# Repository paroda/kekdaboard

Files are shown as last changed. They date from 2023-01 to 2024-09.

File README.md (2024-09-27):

# Custom keyboard

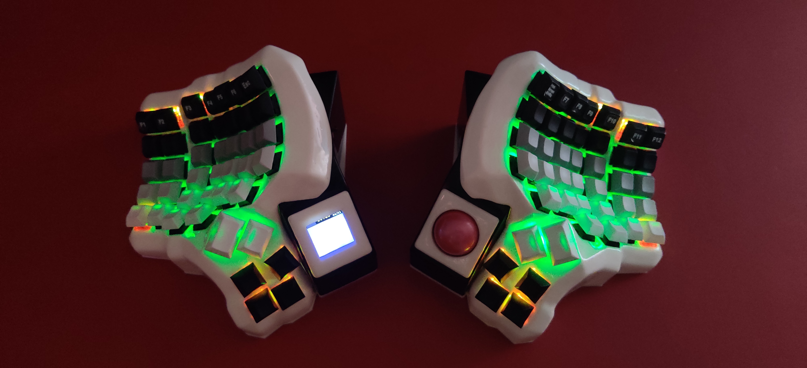
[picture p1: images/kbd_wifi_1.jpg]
WiFi/BLE


This is my custom keyboard, using a set of 3 Raspberry PI Pico W. One for each node and another
serving as the usb dongle. The dongle acts as the BLE central while each node acts as BLE
peripheral.

The WiFi is enabled too, for updating the program. For that the dongle also starts a wifi
access point for a limited time (10 minutes) at start up. However, the nodes by default
doesn't start the wifi mode. But, keeping any key pressed at power on, will make start the
wifi and connect to this access point. Then, the new program can be sent over TCP from
any computer by connecting the same access point.

The left node, includes the LCD display to enbale a basic UI for adjusting the settings.
The right node, includes the trackball for mouse inputs.
The settings are stored on a flash chip addd to the dongle unit.

Each node has separate LEDs under each key. I need to find good keycaps for best use of them,
though not a priority.

# Hardware components

## Dongle

- 1 x Raspberry PI Pico W
- 1 x 4 MB Flash (W25Q32) for storing settings
- 4 x 10 KΩ resistors (for flash pull ups)
- 2 x 5 KΩ resistors (for LED)
- 1 x pushbutton switch (reset button)
- 2 x LEDs (indicate connection status to left/right node)
- 1 x USB A male socket (convert the picow to dongle)

## Left Node

- 1 x Raspberry PI Pico W
- 42 x diodes
- 42 x key hotswap sockets
- 42 x WS2812 5mmx5mm leds for keys backlight
- 1 x 1.54" LCD 240x240 65K RGB by Waveshare
- 1 x RTC DS3231 (clock with own battery)
- 1 x pushbutton switch (reset button)
- 1 x LED (Numlock/connection status)
- 1 x 3.3V to 5V logic converter
- 10 x 10 KΩ resistors (pull ups)
- 1 x 500 Ω resistor (series resistor for the WS2812 led chain)
- 1 x 5 KΩ resistor (for LED indicator)
- 2 x 7x2 pin FRC female connector
- 1 x 14 pin FRC cable with both side 7x2 pin FRC male connector
- 8 bit header pins
- 1 x 3mmx7mm double sided perforated board
- 1 x 1000 µF capacitor for key backlight leds
- 1 x 470 µF capacitor on 3.3V output from Pico
- 1 x 2A 5V output BMS 1S and a 3.7V LiPo battery
- ample amount of magnet wire for the wiring

## Right Node

- 1 x Raspberry PI Pico W
- 42 x diodes
- 42 x key hotswap sockets
- 42 x WS2812 5mmx5mm leds for keys backlight
- 1 x PMW3389 motion sensor for track ball
- 1 x pushbutton switch (reset button)
- 1 x LED (Capslock/connection status)
- 1 x 3.3V to 5V logic converter
- 10 x 10 KΩ resistors (pull ups)
- 1 x 500 Ω resistor (series resistor for the WS2812 led chain)
- 1 x 5 KΩ resistor (for LED indicator)
- 2 x 7x2 pin FRC female connector
- 1 x 14 pin FRC cable with both side 7x2 pin FRC make connector
- 8 bit header pins
- 1 x 3mmx7mm double sided perforated board
- 1 x 1000 µF capacitor for key backlight leds
- 1 x 470 µF capacitor on 3.3V output from Pico
- 1 x 2A 5V output BMS 1S and a 3.7V LiPo battery
- ample amount of magnet wire for the wiring

# Dependency

## Install build tools (Archlinux)

```sh
sudo pacman -Syu base-devel cmake
sudo pacman -Sy arm-none-eabi-binutils arm-none-eabi-gcc arm-none-eabi-newlib
```

## Submodules

Download the submodules
- [pico-sdk](https://github.com/raspberrypi/pico-sdk)
- [pico_fota_bootloader](https://github.com/JZimnol/pico_fota_bootloader)

``` sh
git submodule update --init --recursive
```

# TODO

Need to update the wiring diagrams, which are still the old ones used for the two node wired version.
Since, now I am using the wireless mode, and removed a few redundant hardware components, the wiring
is much simpler now.

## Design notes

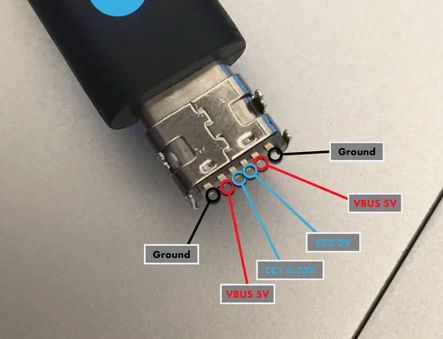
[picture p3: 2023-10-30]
resources/usb-c-pinout.png

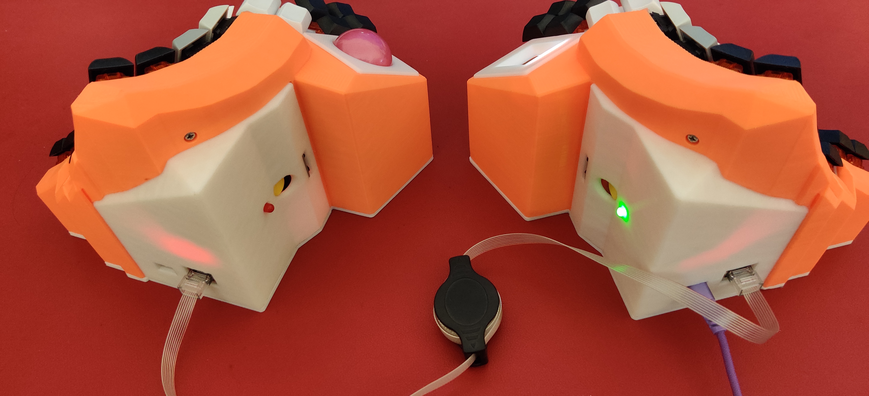
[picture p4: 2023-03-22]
images/kbd_back.jpg

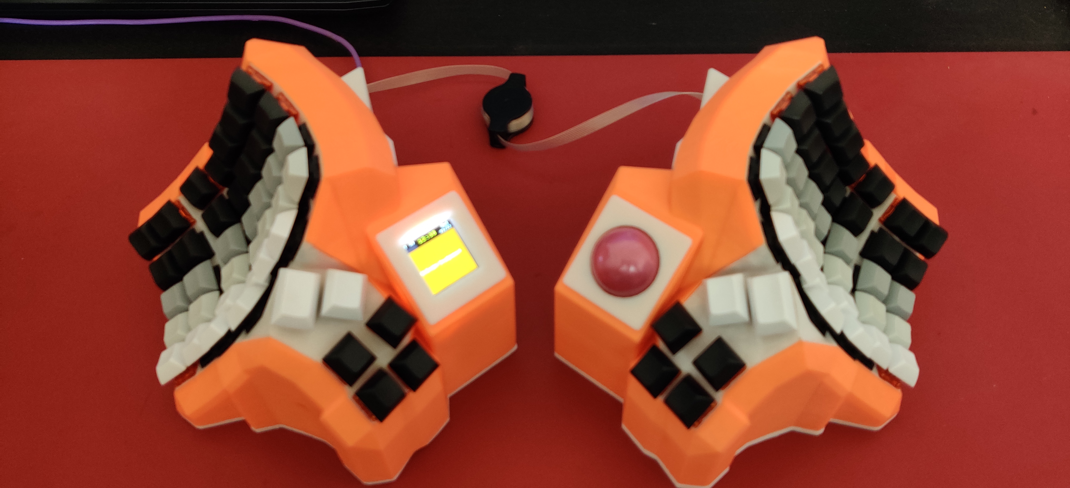
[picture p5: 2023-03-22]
images/kbd_front.jpg

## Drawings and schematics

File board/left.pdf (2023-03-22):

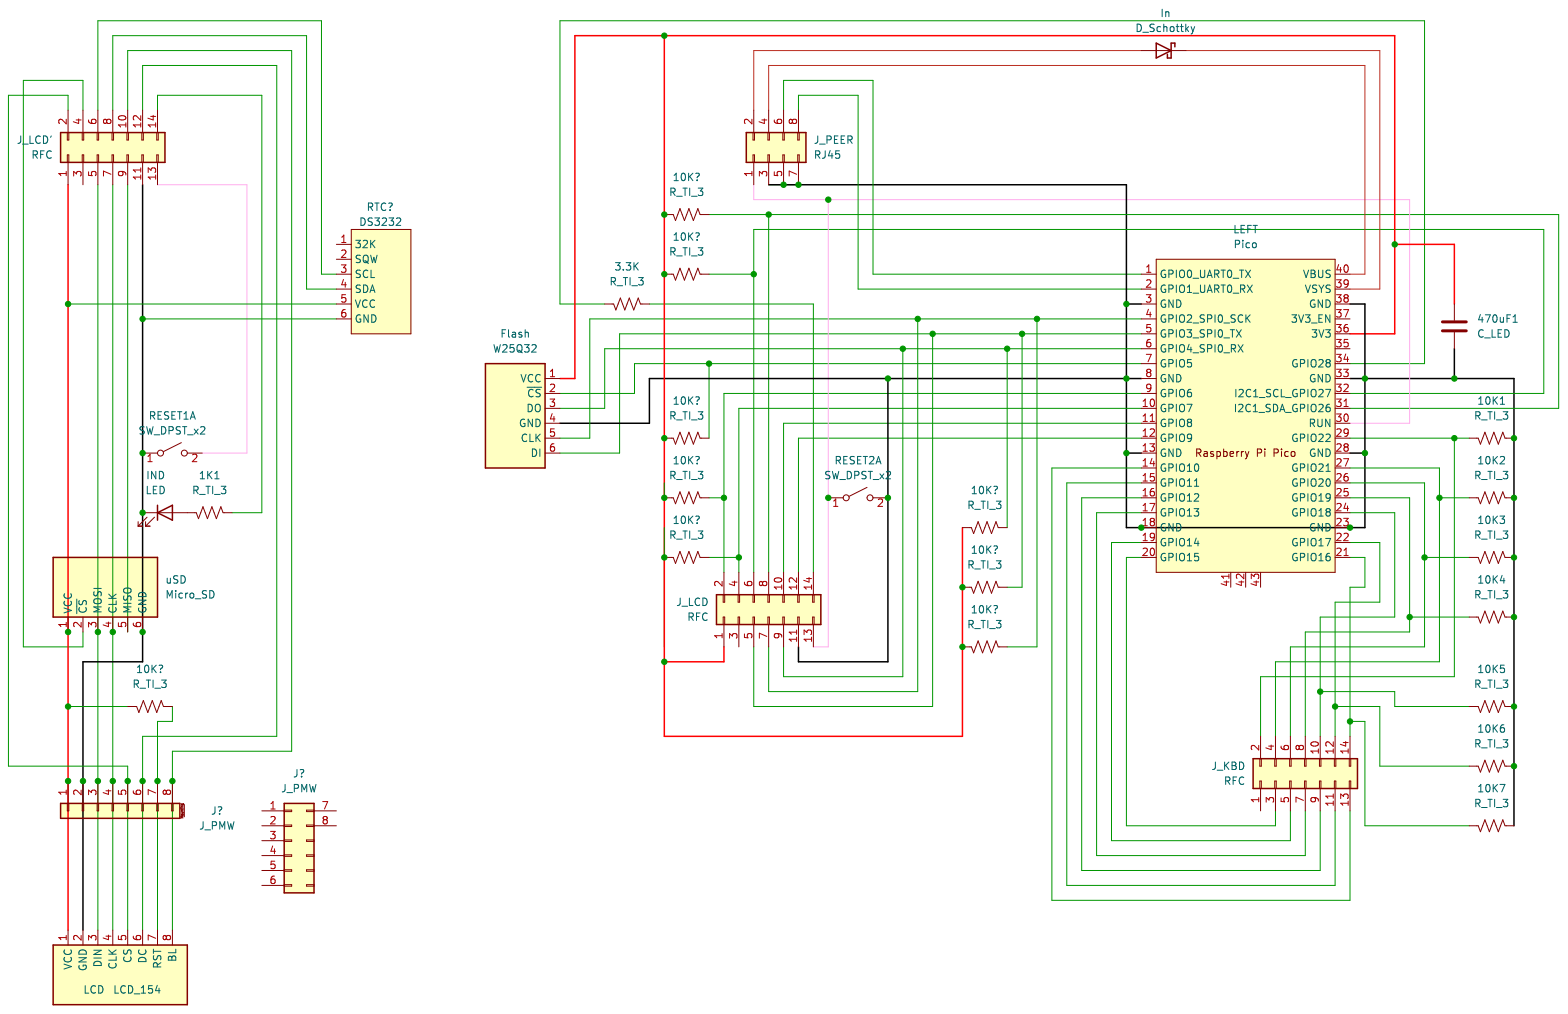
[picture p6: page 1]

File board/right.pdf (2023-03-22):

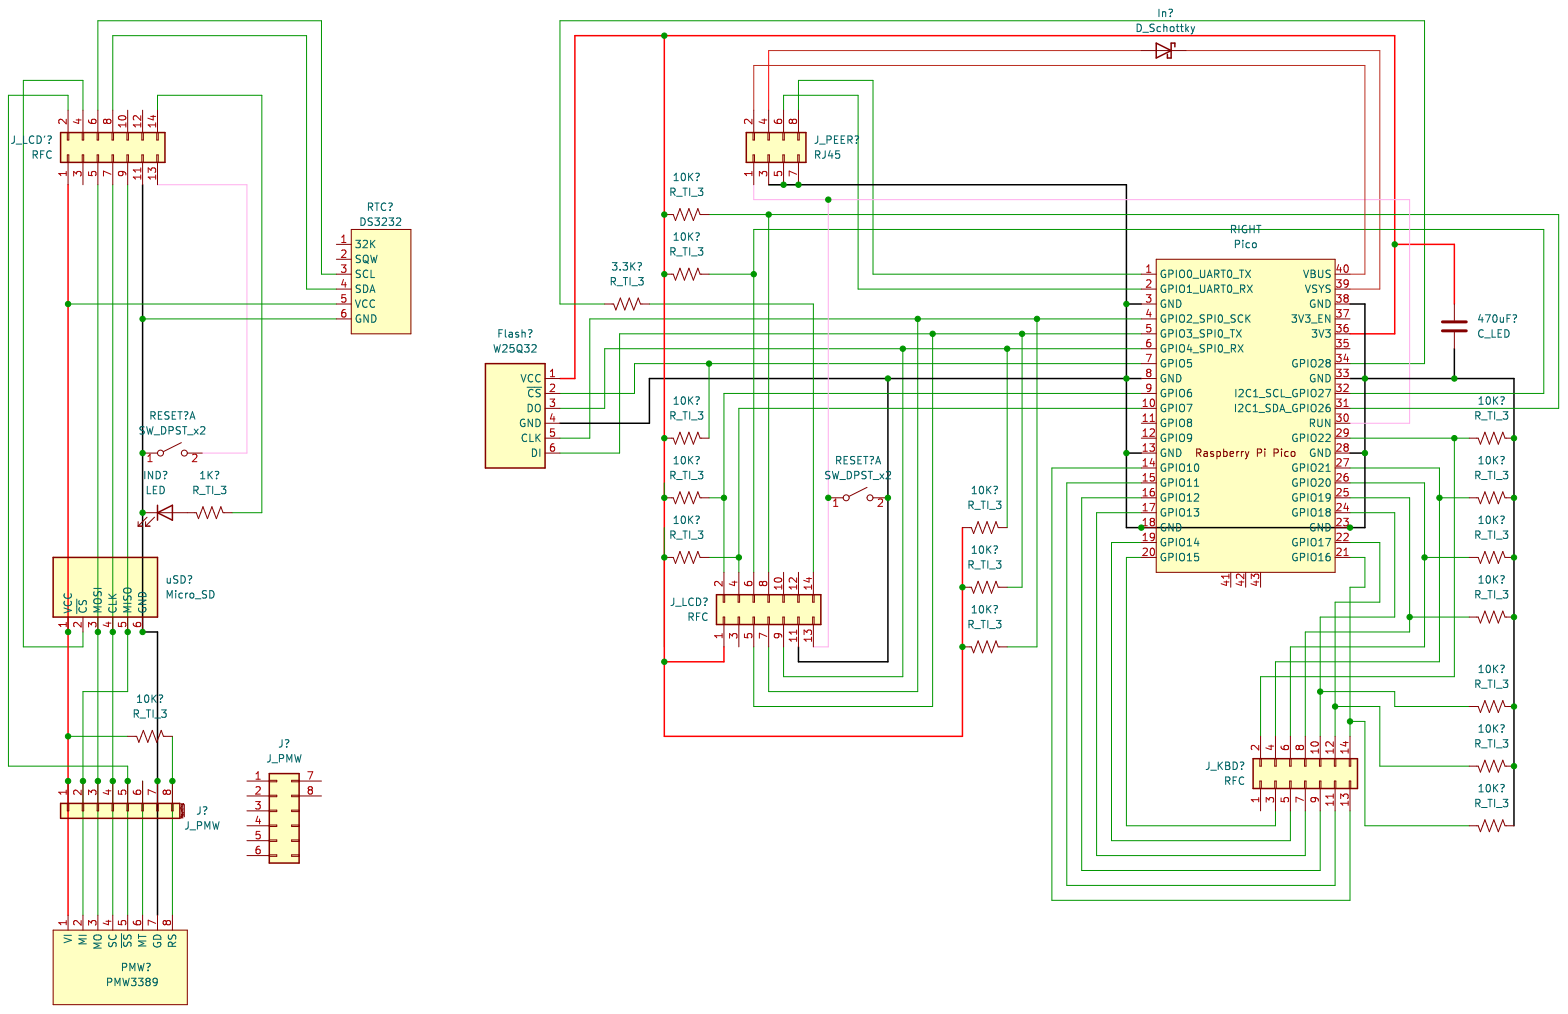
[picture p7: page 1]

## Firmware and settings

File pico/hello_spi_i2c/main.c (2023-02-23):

#include <stdio.h>
#include <string.h>
#include <stdbool.h>

#include "pico/stdlib.h"
#include "../kbd/master_spi.h"
#include "../kbd/flash_w25qxx.h"
#include "../kbd/rtc_ds3231.h"

#include "blink_led.h"

void init_btn_action(uint8_t gpio_BTN) {
    gpio_init(gpio_BTN);
    gpio_set_dir(gpio_BTN, GPIO_IN);
}

bool scan_btn_action(uint8_t gpio_BTN) {
    static bool press = false;
    bool action = false;
    if(gpio_get(gpio_BTN)) {
        if(!press) action = true;
        press = true;
    } else {
        press = false;
    }
    return action;
}

void printbuf(uint8_t* buf, size_t len) {
    for(int i=0; i<len; i++) {
        if(i%16 == 15)
            printf("%02x\n", buf[i]);
        else if(i%4 == 3)
            printf("%02x, ", buf[i]);
        else
            printf("%02x ", buf[i]);
    }
}

void task_flash_action1(flash_t* f) {
    printf("\nTask Flash Action 1");
    uint64_t start_us, end_us, dt;

    start_us = time_us_64();
    flash_sector_erase(f, 0);
    end_us = time_us_64();
    dt = end_us - start_us;
    printf("\nErase sector (%llu us)\n", dt); // ~ 90 ms

    uint8_t buf[FLASH_PAGE_SIZE];
    memset(buf, 0, FLASH_PAGE_SIZE);
    flash_read(f, 0, buf, FLASH_PAGE_SIZE);
    printf("\nRead\n");
    printbuf(buf, FLASH_PAGE_SIZE);

    buf[0]   = 0x01;
    buf[128] = 0x02;
    buf[251] = 0x81;
    buf[255] = 0xAB;
    start_us = time_us_64();
    flash_page_program(f, 0, buf, FLASH_PAGE_SIZE);
    end_us = time_us_64();
    dt = end_us - start_us;
    printf("\nProgram full page (%llu us)\n", dt); // ~ 300 us

    memset(buf, 0, FLASH_PAGE_SIZE);
    flash_read(f, 0, buf, FLASH_PAGE_SIZE);
    printf("\nRead\n");
    printbuf(buf, FLASH_PAGE_SIZE);
}

void task_flash_action2(flash_t* f) {
    printf("\nTask Flash Action 2");
    uint64_t start_us, end_us, dt;

    uint8_t buf[FLASH_PAGE_SIZE];

    start_us = time_us_64();
    flash_sector_erase(f, 0);
    end_us = time_us_64();
    dt = end_us - start_us;
    printf("\nErase sector (%llu us)\n", dt);

    buf[0] = 0; buf[1] = 1; buf[2] = 2; buf[3] = 3;
    start_us = time_us_64();
    flash_page_program(f, 0, buf, 4);
    end_us = time_us_64();
    dt = end_us - start_us;
    printf("\nProgram 4-bytes (%llu us)\n", dt);

    buf[0] = 0x80; buf[1] = 0x81; buf[2] = 0x82; buf[3] = 0x83;
    flash_page_program(f, 4, buf, 4);
    flash_page_program(f, 128, buf, 4);

    buf[0] = 0xF0; buf[1] = 0xF1; buf[2] = 0xF2; buf[3] = 0xF3;
    flash_page_program(f, 8, buf, 4);
    flash_page_program(f, 252, buf, 4);

    memset(buf, 0, FLASH_PAGE_SIZE);
    flash_read(f, 0, buf, FLASH_PAGE_SIZE);
    printf("\nRead\n");
    printbuf(buf, FLASH_PAGE_SIZE);

    // once set to 0, program cannot set it to 1
    // program only sets 1 to 0
    // to set back to 1, only option is to erase

    // try setting all 0xff
    memset(buf, 0xff, FLASH_PAGE_SIZE);
    start_us = time_us_64();
    flash_page_program(f, 0, buf, FLASH_PAGE_SIZE);
    end_us = time_us_64();
    dt = end_us - start_us;
    printf("\nProgram full page 0xff (%llu us)\n", dt);

    buf[0] = 0xF0; buf[1] = 0xF1; buf[2] = 0xF2; buf[3] = 0xF3;
    flash_page_program(f, 12, buf, 4);
    flash_page_program(f, 244, buf, 4);

    memset(buf, 0, FLASH_PAGE_SIZE);
    flash_read(f, 0, buf, FLASH_PAGE_SIZE);
    printf("\nRead\n");
    printbuf(buf, FLASH_PAGE_SIZE);

    // try setting all 0x00
    memset(buf, 0x00, FLASH_PAGE_SIZE);
    start_us = time_us_64();
    flash_page_program(f, 0, buf, FLASH_PAGE_SIZE);
    end_us = time_us_64();
    dt = end_us - start_us;
    printf("\nProgram full page 0x00 (%llu us)\n", dt);

    buf[0] = 0xF0; buf[1] = 0xF1; buf[2] = 0xF2; buf[3] = 0xF3;
    flash_page_program(f, 16, buf, 4);
    flash_page_program(f, 240, buf, 4);

    memset(buf, 0, FLASH_PAGE_SIZE);
    flash_read(f, 0, buf, FLASH_PAGE_SIZE);
    printf("\nRead\n");
    printbuf(buf, FLASH_PAGE_SIZE);
}

void task_flash_action3(flash_t* f) {
    printf("\nTask Flash Action 3");
    uint64_t start_us, end_us, dt;

    uint8_t buf[FLASH_PAGE_SIZE];

    // try 32K block erase

    start_us = time_us_64();
    flash_block_erase_32K(f, 64*1024);
    end_us = time_us_64();
    dt = end_us - start_us;
    printf("\nErase block 32K (%llu us)\n", dt);

    buf[0] = 0; buf[1] = 1; buf[2] = 2; buf[3] = 3;
    flash_page_program(f, 0, buf, 4);

    memset(buf, 0, FLASH_PAGE_SIZE);
    flash_read(f, 0, buf, 4);
    printf("\nRead 4 bytes: %u %u %u %u", buf[0], buf[1], buf[2], buf[3]);

    // try 64K block erase

    start_us = time_us_64();
    flash_block_erase_64K(f, 2*64*1024);
    end_us = time_us_64();
    dt = end_us - start_us;
    printf("\nErase block 64K (%llu us)\n", dt);

    buf[0] = 0x80; buf[1] = 0x81; buf[2] = 0x82; buf[3] = 0x83;
    flash_page_program(f, 0, buf, 4);

    memset(buf, 0, FLASH_PAGE_SIZE);
    flash_read(f, 0, buf, 4);
    printf("\nRead 4 bytes: %u %u %u %u", buf[0], buf[1], buf[2], buf[3]);

    // try chip erase

    start_us = time_us_64();
    flash_chip_erase_all(f);
    end_us = time_us_64();
    dt = end_us - start_us;
    printf("\nErase chip whole (%llu us)\n", dt);

    buf[0] = 0x80; buf[1] = 0x81; buf[2] = 0x82; buf[3] = 0x83;
    flash_page_program(f, 0, buf, 4);

    memset(buf, 0, FLASH_PAGE_SIZE);
    flash_read(f, 0, buf, 4);
    printf("\nRead 4 bytes: %u %u %u %u", buf[0], buf[1], buf[2], buf[3]);

}

void task_flash(flash_t* f, bool* action) {
    static uint32_t interval_ms = 5000;
    static uint32_t start_ms = 0;
    if(start_ms == 0) start_ms = board_millis();

    uint8_t buf[FLASH_PAGE_SIZE];
    memset(buf, 0, FLASH_PAGE_SIZE);
    uint32_t addr = 0;
    uint64_t start_us, end_us, dt;

    if(board_millis() - start_ms > interval_ms) {
        start_ms += interval_ms;

        uint32_t id = flash_get_id(f);
        printf("\n\nFlash device ID: %#010x\n", id);

        uint32_t baud = spi_get_baudrate(f->m_spi->spi);
        printf("\nBaud: %lu", baud);

        start_us = time_us_64();
        flash_read(f, addr, buf, FLASH_PAGE_SIZE);
        end_us = time_us_64();
        dt = end_us - start_us;
        printf("\nRead full page (%llu us): addr(%lu) size(%lu)\n", dt, addr, FLASH_PAGE_SIZE);
        printbuf(buf, FLASH_PAGE_SIZE);

        memset(buf, 0, FLASH_PAGE_SIZE);
        start_us = time_us_64();
        flash_read(f, addr, buf, 4);
        end_us = time_us_64();
        dt = end_us -start_us;
        printf("\nRead 4-bytes (%llu us): %u %u %u %u", dt, buf[0], buf[1], buf[2], buf[3]);

        if(*action) {
            task_flash_action2(f);
            *action = false;
        }
    }

}

void print_datetime(rtc_datetime_t* dt) {
    printf("%d-%02d-%02d (%d:%s) %02d:%02d:%02d",
           dt->year, dt->month, dt->date,
           dt->weekday, rtc_week[dt->weekday],
           dt->hour, dt->minute, dt->second);
}

void task_rtc(rtc_t* rtc, bool* action) {
    static uint32_t interval_ms = 5000;
    static uint32_t start_ms = 0;
    if(start_ms == 0) start_ms = board_millis();

    rtc_datetime_t dt;
    int8_t temp;
    if(board_millis() - start_ms > interval_ms) {
        start_ms += interval_ms;
        printf("\n\nRTC Trials");

        rtc_read_time(rtc, &dt);
        printf("\nRTC time: "); print_datetime(&dt);
        temp = rtc_get_temperature(rtc);
        printf("\nRTC temperature: %d", temp);

        if(*action) {
            // TODO: action
            dt.year = 2023;
            dt.month = 2;
            dt.date = 16;
            dt.weekday = 5;
            dt.hour = 13;
            dt.minute = 20;
            dt.second = 0;
            rtc_set_time(rtc, &dt);
            *action = false;
        }
    }
}

int main(void) {
    stdio_init_all();

    sleep_ms(5000);
    printf("\nHello from PICO. Booting up..");

    // master SPI
    uint8_t gpio_CLK = 2; // GP2 SPI0 SCK
    uint8_t gpio_MOSI = 3; // GP3 SPI0 TX
    uint8_t gpio_MISO = 4; // GP4 SPI0 RX

    // flash
    uint8_t gpio_CS_w25qxx  = 5; // GP5

    // SD card
    uint8_t gpio_CS_sd_card  = 7; // GP7

    // RTC
    uint8_t gpio_SCL = 27; // GP27 I2C1 SCL
    uint8_t gpio_SDA = 26; // GP26 I2C1 SDA

    uint8_t gpio_BTN = 15; // GP15 action button
    init_btn_action(gpio_BTN);

    master_spi_t* m_spi = master_spi_create(spi0, 2, gpio_MOSI, gpio_MISO, gpio_CLK);

    flash_t* f = flash_create(m_spi, gpio_CS_w25qxx);

    rtc_t* r = rtc_create(i2c1, gpio_SCL, gpio_SDA);

    while(true) {
        sleep_ms(1);
        led_blinking_task();

        static bool action_flash = false;
        static bool action_rtc = false;
        if(scan_btn_action(gpio_BTN)) {
            action_rtc = true;
        }

        static uint32_t start_ms = 0;
        if(start_ms == 0) start_ms = board_millis();

        if(board_millis() - start_ms > 1000) {
            spi_set_baudrate(m_spi->spi, 125*1000*1000);
            start_ms += 1000;

            printf("\nHello again from PICO. still beating..");
            //print_master_spi(m_spi);

            task_flash(f, &action_flash);

            task_rtc(r, &action_rtc);
        }

        tight_loop_contents();
    }
}

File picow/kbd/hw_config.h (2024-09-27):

#ifndef _HW_CONFIG_H
#define _HW_CONFIG_H

#include <stdint.h>  // common include
#include <stdbool.h> // common include

#include "main.h"    // common include

#define hw_ap_name "kekdaboard"
#define hw_ap_password "3picowkbd"
#define hw_udp_port 81
#define hw_tcp_port 82
#define hw_tcp_poll_time_s 5

#define hw_led_pixel_count 42 // each side

//////////////////////////////////////////////////////////// ACCESS POINT

#ifdef KBD_NODE_AP

#define hw_inst_SPI 0
#define hw_gpio_CLK 6
#define hw_gpio_MOSI 7
#define hw_gpio_MISO 4

#define hw_gpio_CS_flash 5
#define hw_gpio_LED_LEFT 10
#define hw_gpio_LED_RIGHT 21

#define hw_row_count 6
#define hw_col_count 7

#endif

//////////////////////////////////////////////////////////// LEFT NODE

#ifdef KBD_NODE_LEFT

#define hw_inst_SPI 0
#define hw_gpio_CLK 2
#define hw_gpio_MOSI 3
#define hw_gpio_MISO 4

#define hw_inst_I2C 1
#define hw_gpio_SCL 27
#define hw_gpio_SDA 26

#define hw_gpio_CS_sd_card 5

#define hw_gpio_LED 28

// lcd
#define hw_gpio_CS_lcd 7
#define hw_gpio_lcd_BL 8
#define hw_gpio_lcd_DC 9
#define hw_gpio_lcd_RST 0xFF // use software RESET

// key scan layout
#define hw_row_count 6
#define hw_col_count 7
#define hw_gpio_rows  {10, 11, 12, 13, 14, 15} // 6 rows
#define hw_gpio_cols {16, 17, 18, 19, 20, 21, 22} // 7 cols

// key pixels
#define hw_inst_PIO 0
#define hw_inst_PIO_SM 0
#define hw_gpio_led_DI 6
#define hw_key_led_mapping {                    \
        { 0,  1,  2,  3,  4,  5,  6},           \
        {13, 12, 11, 10,  9,  8,  7}            \
        {14, 15, 16, 17, 18, 19, 20}            \
        {27, 26, 25, 24, 23, 22, 21}            \
        {28, 29, 30, 31, 32, 33, 34}            \
        {41, 40, 39, 38, 37, 36, 35}            \
    }

#endif

//////////////////////////////////////////////////////////// RIGHT NODE

#ifdef KBD_NODE_RIGHT

#define hw_inst_SPI 0
#define hw_gpio_CLK 2
#define hw_gpio_MOSI 3
#define hw_gpio_MISO 4

#define hw_gpio_LED 28

// trackball
#define hw_gpio_CS_tb 7
#define hw_gpio_tb_MT 0xFF  // not used
#define hw_gpio_tb_RST 0xFF // not used

// key scan layout
#define hw_row_count 6
#define hw_col_count 7
#define hw_gpio_rows  {21, 20, 19, 18, 17, 16} // 6 rows
#define hw_gpio_cols {9, 10, 11, 12, 13, 14, 15} // 7 cols

// key pixels
#define hw_inst_PIO 0
#define hw_inst_PIO_SM 0
#define hw_gpio_led_DI 6
#define hw_key_led_mapping {                    \
        { 6,  5,  4,  3,  2,  1,  0},           \
        { 7,  8,  9, 10, 11, 12, 13}            \
        {20, 19, 18, 17, 16, 15, 14}            \
        {21, 22, 23, 24, 25, 26, 27}            \
        {34, 33, 32, 31, 30, 29, 28}            \
        {35, 36, 37, 38, 39, 40, 41}            \
    }

#endif


#endif

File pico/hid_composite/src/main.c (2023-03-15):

/*
 * The MIT License (MIT)
 *
 * Copyright (c) 2019 Ha Thach (tinyusb.org)
 *
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
 */

#include <stdlib.h>
#include <stdio.h>
#include <string.h>

#include "bsp/board.h"
#include "tusb.h"

#include "usb_descriptors.h"

#include "pico/stdlib.h"
#include "hardware/gpio.h"

#include "layouts.h"

//--------------------------------------------------------------------+
// MACRO CONSTANT TYPEDEF PROTYPES
//--------------------------------------------------------------------+

// blink interval in milliseconds to indicate device status
enum
{
  BLINK_NOT_MOUNTED = 100,
  BLINK_MOUNTED = 1000,
  BLINK_SUSPENDED = 3000,
};

static uint32_t blink_interval_ms = BLINK_NOT_MOUNTED;

static void led_blinking_task(void);
static void hid_init(void);
static void hid_task(void);

static uint8_t kbd_modifiers = 0;
static uint8_t kbd_btns[6] = {0, 0, 0, 0, 0, 0};
static uint kbd_btns_count = 0;
static bool kbd_has_btns = false;
static bool kbd_had_keys = false;
static bool kbd_had_consumer_keys = false;

static bool kbd_num_lock_on = false;
static kbd_layer kbd_active_layer = KBD_LAYER_BASE;

/*------------- MAIN -------------*/
int main(void)
{
  board_init();

  // init device stack on configured roothub port
  tud_init(BOARD_TUD_RHPORT);

  hid_init();

  while (1)
  {
    tud_task(); // tinyusb device task
    led_blinking_task();
    hid_task();
  }

  return 0;
}

//--------------------------------------------------------------------+
// Device callbacks
//--------------------------------------------------------------------+

// Invoked when device is mounted
void tud_mount_cb(void)
{
  blink_interval_ms = BLINK_MOUNTED;
}

// Invoked when device is unmounted
void tud_umount_cb(void)
{
  blink_interval_ms = BLINK_NOT_MOUNTED;
}

// Invoked when usb bus is suspended
// remote_wakeup_en : if host allow us  to perform remote wakeup
// Within 7ms, device must draw an average of current less than 2.5 mA from bus
void tud_suspend_cb(bool remote_wakeup_en)
{
  (void)remote_wakeup_en;
  blink_interval_ms = BLINK_SUSPENDED;
}

// Invoked when usb bus is resumed
void tud_resume_cb(void)
{
  blink_interval_ms = BLINK_MOUNTED;
}

static void send_hid_kbd_report()
{
  if (kbd_has_btns)
  {
    tud_hid_keyboard_report(REPORT_ID_KEYBOARD, kbd_modifiers, kbd_btns);
    kbd_had_keys = true;
  }
  else
  {
    // send key report if previously has key pressed
    if (kbd_had_keys)
      tud_hid_keyboard_report(REPORT_ID_KEYBOARD, kbd_modifiers, kbd_btns);
    kbd_had_keys = false;
  }
}

static void send_hid_consumer_report()
{
  static bool mute_was_pressed = false;
  uint16_t consumer_key = 0;
  uint8_t btn = 0;

  if (kbd_has_btns)
  {
    for (uint i = 0; i < kbd_btns_count && !btn; i++)
    {
      btn = kbd_btns[i];
      switch (btn)
      {
      case HID_KEY_VOLUME_DOWN:
        consumer_key = HID_USAGE_CONSUMER_VOLUME_DECREMENT;
        break;
      case HID_KEY_VOLUME_UP:
        consumer_key = HID_USAGE_CONSUMER_VOLUME_INCREMENT;
        break;
      case HID_KEY_MUTE:
        consumer_key = mute_was_pressed ? 0 : HID_USAGE_CONSUMER_MUTE;
        break;
      default:
        btn = 0;
        break;
      }
    }
  }

  mute_was_pressed = btn == HID_KEY_MUTE;

  if (consumer_key)
  {
    tud_hid_report(REPORT_ID_CONSUMER_CONTROL, &consumer_key, 2);
    kbd_had_consumer_keys = true;
  }
  else
  {
    uint16_t empty_key = 0;
    if (kbd_had_consumer_keys)
      tud_hid_report(REPORT_ID_CONSUMER_CONTROL, &empty_key, 2);
    kbd_had_consumer_keys = false;
  }
}

static void send_hid_report(uint8_t report_id)
{
  if (!tud_hid_ready())
    return; //skip if hid is not ready yet

  // NOTE: you must send report for all previous reports in report id sequence
  //       otherwise your target report will never get called.
  //       For example, if you do not send the mouse report, then there would be
  //       no completion callback to send the next report which is consumer control.
  switch (report_id)
  {
  case REPORT_ID_KEYBOARD:
    send_hid_kbd_report();
    break;

  case REPORT_ID_MOUSE:
    // arguments: button = 0x00 - no button
    //            delta-right = 0, delta-down = 0
    //            scroll = 0, pan = 0
    tud_hid_mouse_report(REPORT_ID_MOUSE, 0x00, 0, 0, 0, 0);
    break;

  case REPORT_ID_CONSUMER_CONTROL:
    send_hid_consumer_report();
    break;

  case REPORT_ID_GAMEPAD:
    break;

  default:
    break;
  }
}

static void kbd_read_num_layer_btn(bool pressed)
{
  static bool was_pressed = false;

  if (!was_pressed && pressed)
  {
    kbd_active_layer = kbd_active_layer == KBD_LAYER_NUM ? KBD_LAYER_BASE : KBD_LAYER_NUM;
    bool num = kbd_active_layer == KBD_LAYER_NUM;
    gpio_put(kbd_led_num_layer_gpio, num);
    // also set the num lock on
    if (kbd_num_lock_on != num && kbd_btns_count<6) kbd_btns[kbd_btns_count++]=HID_KEY_NUM_LOCK;
  }

  was_pressed = pressed;
}

static void kbd_read_btn(const uint8_t key[2], bool pressed)
{
  uint8_t flag = key[0];
  uint8_t code = key[1];

  // read modifier flag
  if (pressed && flag)
  {
    kbd_modifiers |= flag;
  }

  // unassigned keys
  if (code == 0)
  {
    return;
  }

  // special key - num layer
  if (code == KBD_KEY_NUM_LAYER)
  {
    kbd_read_num_layer_btn(pressed);
    return;
  }

  // regular keys
  if (pressed && kbd_btns_count < 6)
  {
    kbd_btns[kbd_btns_count++] = code;
  }
}

static void kbd_buttons_read()
{
  for (uint row = 0; row < KBD_ROW_COUNT; row++)
  {
    uint row_gpio = kbd_layout_row_gpio[row];
    gpio_put(row_gpio, true);

    for (uint col = 0; col < KBD_COL_COUNT; col++)
    {
      uint col_gpio = kbd_layout_col_gpio[col];
      kbd_read_btn(kbd_layouts[kbd_active_layer][row][col], gpio_get(col_gpio));
    }

    gpio_put(row_gpio, false);
  }
}

// initialize GPIO pins
static void hid_init(void)
{

  uint i, gpio;

  // set led out pins - out
  gpio = kbd_led_caps_lock_gpio;
  gpio_init(gpio);
  gpio_set_dir(gpio, GPIO_OUT);

  gpio = kbd_led_num_lock_gpio;
  gpio_init(gpio);
  gpio_set_dir(gpio, GPIO_OUT);

  gpio = kbd_led_num_layer_gpio;
  gpio_init(gpio);
  gpio_set_dir(gpio, GPIO_OUT);

  // set row pins - out
  for (i = 0; i < KBD_ROW_COUNT; i++)
  {
    gpio = kbd_layout_row_gpio[i];
    gpio_init(gpio);
    gpio_set_dir(gpio, GPIO_OUT);
  }

  // set col pins - in
  for (i = 0; i < KBD_COL_COUNT; i++)
  {
    gpio = kbd_layout_col_gpio[i];
    gpio_init(gpio);
    gpio_set_dir(gpio, GPIO_IN);
  }
}
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

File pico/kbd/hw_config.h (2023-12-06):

#ifndef _HW_CONFIG_H
#define _HW_CONFIG_H

#include <stdint.h>
#include <stdbool.h>

#define hw_inst_UART 0
#define hw_gpio_TX 0
#define hw_gpio_RX 1

#define hw_inst_I2C 1
#define hw_gpio_SCL 27
#define hw_gpio_SDA 26

#define hw_inst_SPI 0
#define hw_gpio_CLK 2
#define hw_gpio_MOSI 3
#define hw_gpio_MISO 4

#define hw_gpio_CS_flash 5
#define hw_gpio_CS_sd_card 7

#define hw_gpio_LED 28

// key scan layout
#define hw_gpio_rows  {15, 14, 13, 12, 11, 10} // 6 rows
#define hw_gpio_cols {22, 21, 20, 19, 18, 17, 16} // 7 cols

// only left side
#define hw_gpio_CS_lcd 6
#define hw_gpio_lcd_BL 8
#define hw_gpio_lcd_DC 9
#define hw_gpio_lcd_RST 0xFF // use software RESET

// only right side
#define hw_gpio_CS_tb 6
#define hw_gpio_tb_MT 0xFF  // not used
#define hw_gpio_tb_RST 0xFF // not used

// only right side
#define hw_inst_PIO 0
#define hw_inst_PIO_SM 0
#define hw_gpio_led_left_DI 8
#define hw_gpio_led_right_DI 9
#define hw_led_pixel_count 42 // each side

// led pixels layout - left
#define hw_key_leds_left { \
    { 0,  1,  2,  3,  4,  5,  6}, \
    {13, 12, 11, 10,  9,  8,  7} \
    {14, 15, 16, 17, 18, 19, 20} \
    {27, 26, 25, 24, 23, 22, 21} \
    {28, 29, 30, 31, 32, 33, 34} \
    {35, 36, 37, 38, 39, 40, 41} \
} // FIX last row

// led pixels layout - right
#define hw_key_leds_right { \
    { 6,  5,  4,  3,  2,  1,  0}, \
    { 7,  8,  9, 10, 11, 12, 13} \
    {20, 19, 18, 17, 16, 15, 14} \
    {21, 22, 23, 24, 25, 26, 27} \
    {34, 33, 32, 31, 30, 29, 28} \
    {35, 36, 37, 38, 39, 40, 41} \
} // FIX last row

#endif

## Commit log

2021-10-16 add layout planned with excel
    [kbd_layout.xlsx]
2021-11-25 use dactyl manuform 6x7
    [kbd_layout.xlsx]
2022-11-20 add trials uart and start next kbd variant
2022-11-22 update .dir-locals.el for pico-sdk
2023-01-01 add track-ball
2023-03-16 basic working - no config screens
    [kbd_layout.xlsx]
2023-03-17 fix state update and event miss
    [data_model.c, main.c]
2023-03-22 enable power config
2023-03-22 add schematics
    [board-left.kicad_sch, board-right.kicad_sch, kbd_layout.xlsx]
2023-03-23 enable power config persistence to flash
2023-10-30 add led per key switch
2023-12-15 fix led pixels
2023-12-16 add led pixels config screen
2023-12-16 fix lingering ESC on config screen exit
    [data_model.c]
2023-12-18 enable toggle key switch led pixels
2023-12-18 fix turning of led pixels
    [led_pixel.c]
2023-12-19 add reset to led pixel immediately after setting new values
    [hw_model.c, led_pixel.c]
2024-04-22 fix track ball scan fequency
2024-09-01 upgrade pico-sdk to 2.0.0
2024-09-26 fix led blink timing
    [hw_model.c]
